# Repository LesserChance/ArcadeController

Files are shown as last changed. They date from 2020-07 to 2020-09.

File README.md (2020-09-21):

# ArcadeController
The goal of this project is to make an easily-swappable control panel for a homebuilt arcade. There are two PCBs that are designed to mate through a ribbon cable connection. By default, this setup will allow for any control panel to have a maximum of 2 joysticks and 14 buttons (22 total digital inputs), 6 axes (e.g. 6 spinners) and two USB devices. You can easily edit the program on the arduino to assure all of your control panels will work, though, for instance if you need more digital inputs and fewer axes.

As I build out more control panels I'll be adding pictures and diagrams of how everything operates.

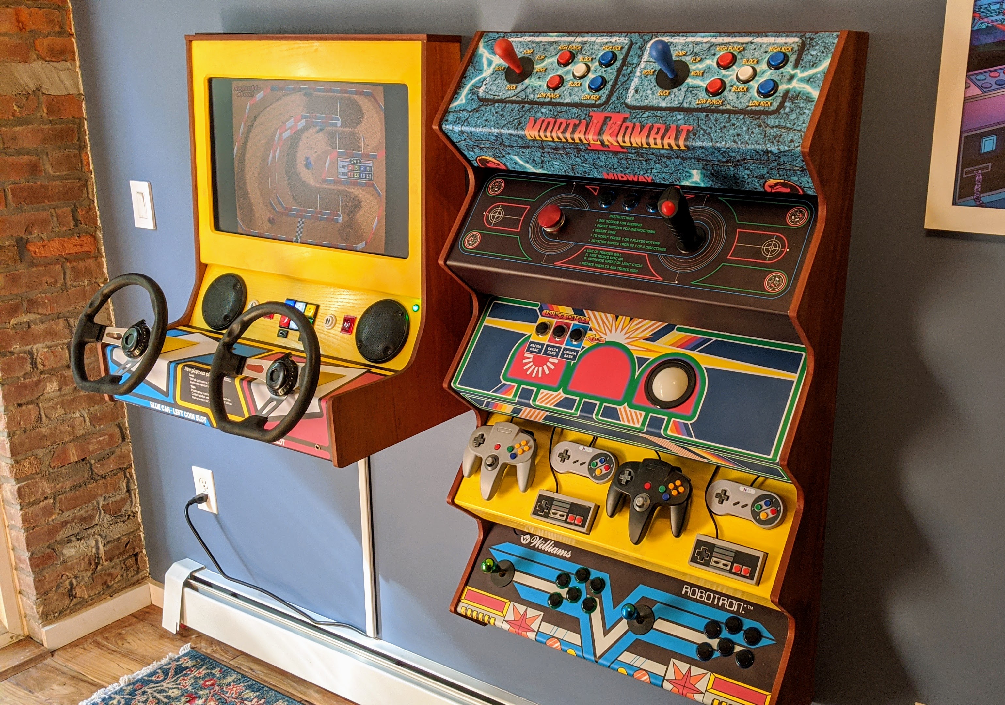
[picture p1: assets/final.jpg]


## Electronics
### PCB: Panel
One Panel PCB exists for each control panel. The Panel PCB exists as the interface between the controls (joysticks, trackballs, spinners, USB devices) and the Main interface. It is split into various sections. Full wiring diagrams can be found in the docs directory.

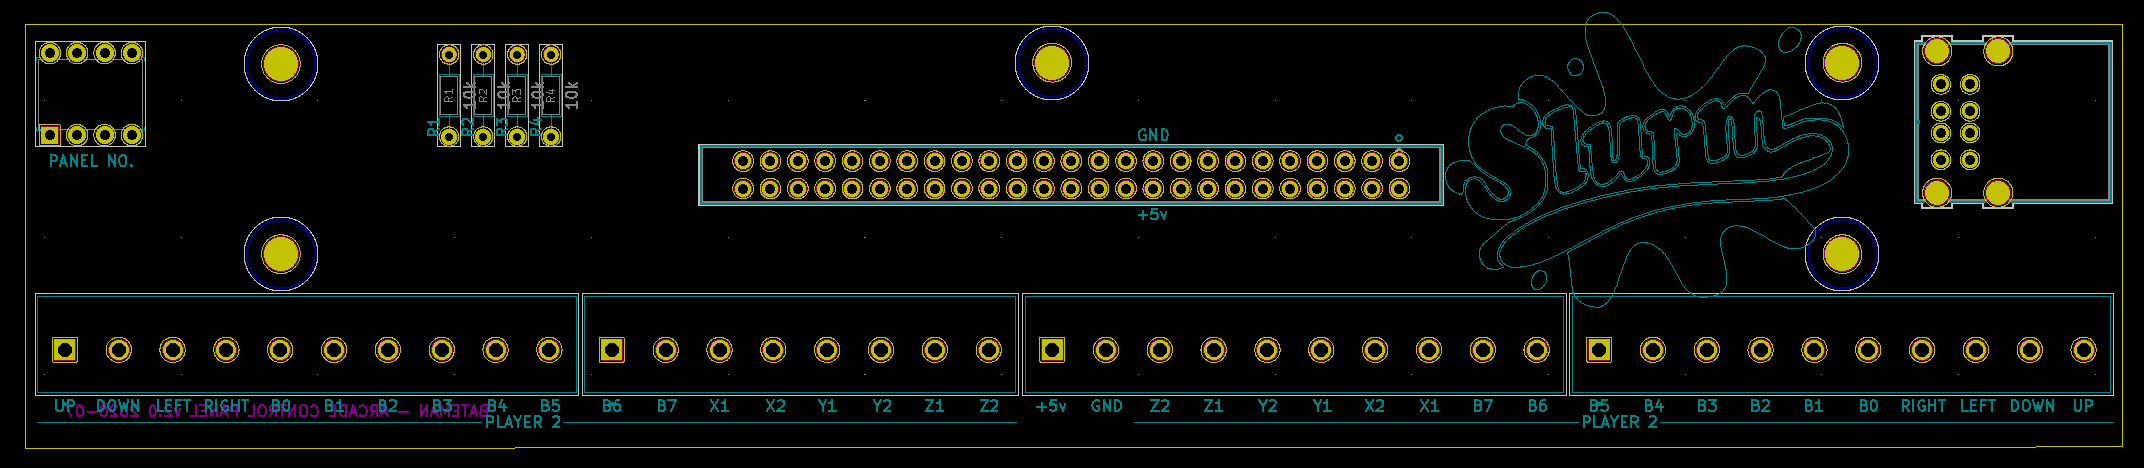
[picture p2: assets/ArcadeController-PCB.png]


**Player One** Connected to "Player One" Micro.  
*Up, Down, Left, Right, B0-5*: Four directional wires, 6 button wires. (note that B6, B7 are not wired to anything)  
*X1, X2, Y1, Y2, Z1, Z2*: These utilize interrupt pins on the arduinos, and are used for encoder connections (trackball, spinner)  

**Player Two** Connected to "Player Two" Micro.  
*Up, Down, Left, Right, B0-5*: Four directional wires, 6 button wires. (note that B6, B7 are not wired to anything)  
*X1, X2, Y1, Y2, Z1, Z2*: These utilize interrupt pins on the arduinos, and are used for encoder connections (trackball, spinner)  

**+5v/Ground** Pulls +5v and Ground from "Player One" Micro. Useful for LEDs/etc

**USB** These directly wire to USB connection on the main control panel. These can be used to directly connect USB devices to your computer. Unfortunately these dont seem to be working just yet!

**DIP switch** Used to identify which control panel this is. Allows for different programming on the arduinos per control panel.  

For detailed wiring information see [the pinmap](docs/pinmap.md).

### PCB: Main

The Main PCB is what connects to your computer through USB. In total it requires four open USB ports. Only One Main PCB is necessary. The main panels houses two Arduino Micros.

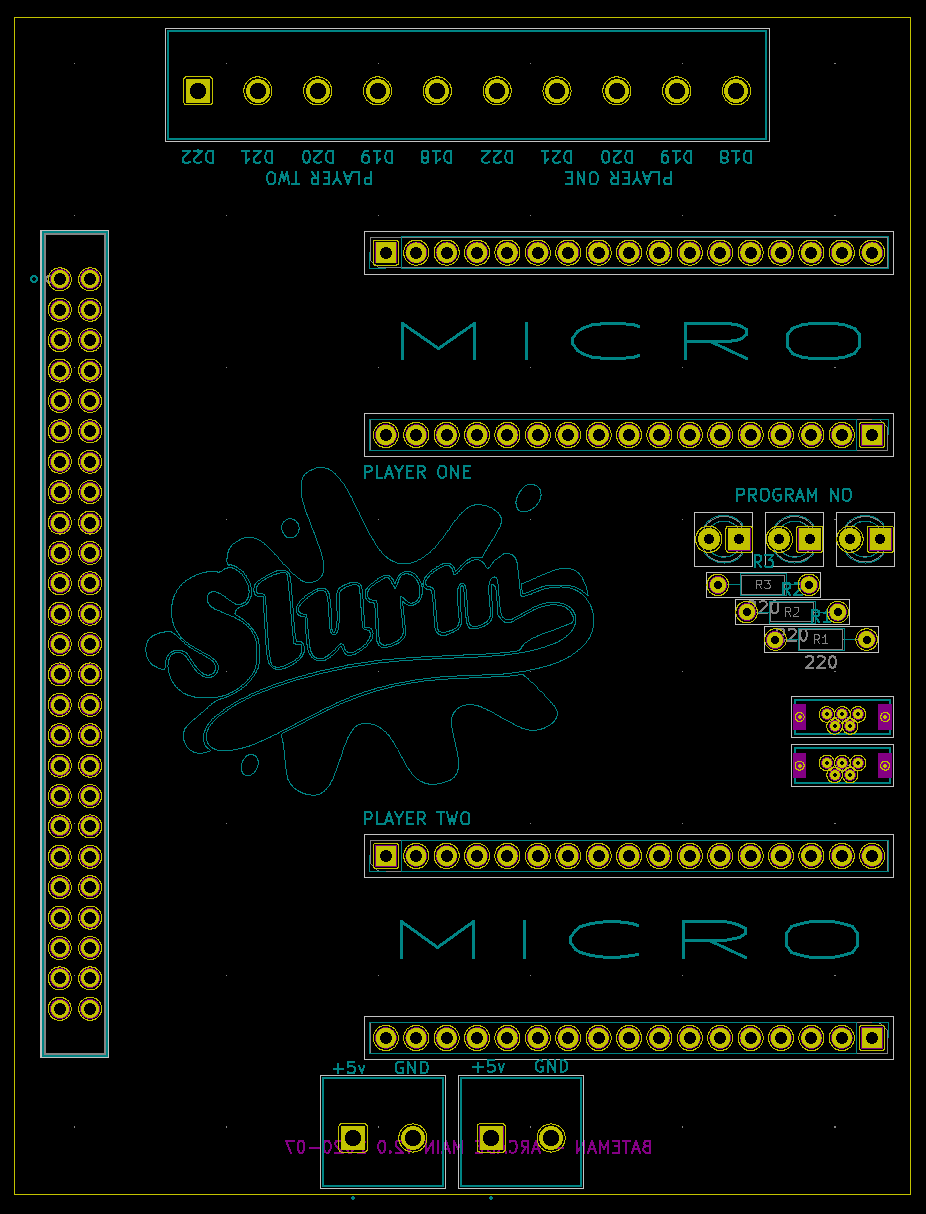
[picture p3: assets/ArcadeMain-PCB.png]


**Micro Headers** These are the positions where you plug in Arduino Micros.

**Screw in Terminals** These can be used for shared functions e.g. Player 1/2 Start/Coin as well as menu or function buttons. 6 are connected to "Player One" Micro, and another 6 are connected to "Player Two" Micro.

### Arduino

The program is built to run on an [Ardunio Micro](https://store.arduino.cc/usa/arduino-micro). Two Arduino Micros are required for two-player functionality. Player One and the two additional USB devices will work fine with just one, though, if you can get away with a maximum of 17 total digital inputs on any control panel.

When plugged in the Arduinos will be treated as a joystick/mouse/keyboard by the computer based on the code used for the control panel. The joystick, by default is 2 axis (X/Y) and 12 button.

---

Schematics were designed in [Kicad](https://kicad-pcb.org/). I print PCBS with [JLCPCB](jlcpcb.com/).

# Documents
### [Pinmap](docs/pinmap.md)
The pinmap outlines how connections are bridged between the PCBs and how they function by default through USB. Panel->Main->Arduino->Function

### [Wiring](docs/wiring.md)
The wiring doc outlines standard wiring for trackballs and spinners directly into the Panel PCB.

# Supplies
_Prices are USD, do not include shipping, and are as of July 2020._

Buy extra screw-in terminals to make more control panels, and buy the Panel PCBs in bulk. Given the below prices you could create 10 easily-swappable control panels for ~$80, and you may be able to find those screw terminals more cheaply, or decide to bypass those, just solder in your connections and have it all for ~$40. Of course the price of buttons/joysticks/trackballs/steering wheels/etc is additional.

| Component | Part | Supply | Cost | Count |
|---|---|---|---|---|
| Main | Arduino Micro | [Ardunio Store](https://store.arduino.cc/usa/arduino-micro-without-headers) | $12.30 | 2 |
| Main | PCB | [JLCPCB](jlcpcb.com/) | $7.00 | 1 (price is per 5 though - _minimum order_) |
| Main | Micro USB | [Digikey](https://www.digikey.com/product-detail/en/molex/0475890001/WM17143CT-ND/1832255) | $.87 | 2 |
| Main | Micro Pin Headers | [Digikey](https://www.digikey.com/product-detail/en/sullins-connector-solutions/PREC040SAAN-RC/S1012EC-40-ND/2774814) | $.51 | 2 |
| Main | Micro connection headers | [Digikey](https://www.digikey.com/product-detail/en/adafruit-industries-llc/598/1528-2537-ND/8299908) | $2.95 | 1 (cut each down to 17 pins) |
| Main | LEDs | Im sure you have some laying around | - | 3 |
| Main | Cable Header | [Digikey](https://www.digikey.com/product-detail/en/assmann-wsw-components/AWH-50G-E232-IDC/AE11157-ND/5050380) | $4.56 | 1 |
| Panel | PCB | [JLCPCB](jlcpcb.com/) | $12.00 | 1 (price was for 10) |
| Panel | USB Header | [Digikey](https://www.digikey.com/product-detail/en/assmann-wsw-components/AU-Y1008-2/AE11131-ND/5147142) | $1.07 | 1 |
| Panel | Ribbon Cable | [Digikey](https://www.digikey.com/product-detail/en/assmann-wsw-components/H3AAH-5018G/H3AAH-5018G-ND/1218717) | $3.27 | 1 |
| Panel | Cable Header | [Digikey](https://www.digikey.com/product-detail/en/sullins-connector-solutions/SBH11-PBPC-D25-ST-BK/S9176-ND/1990069) | $1.02 | 1 |
| Panel | DIP Switch | [Digikey](https://www.digikey.com/product-detail/en/cts-electrocomponents/208-4/CT2084-ND/20783) | $.69 | 1 |
| Main+Panel | Resistors | (3) 10k, 3 (220) | - | 6 |
| Main+Panel | Screw-in Terminal | [Digikey](https://www.digikey.com/products/en?keywords=TB001-500-12BE%20) | $1.73 | 5 (+4 for each additional panel) |

_Why do the PCBs have the Slurm logo on them? I dont know, I just really like Futurama and happened to have this image handy..._

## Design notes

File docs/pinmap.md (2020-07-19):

## Panel PCB
### Joystick
| Controller Input | Arduino | Arduino Pin | Function | Note |
|---|---|---|---|---|
| UP | 1/2 | SS/D17 | Player Up | Pin 17 is used for the LED, and MUST be a pulldown, wire this button to +5v, in retrospect I shouldn't have used this pin, as it looks like it randomly bounces. Ill probably swap it in the arduino code to the z axis pin or something. |
| DOWN | 1/2 | SCL/D3 | Player Down |  |
| LEFT | 1/2 |  A6/D4 | Player Left |  |
| RIGHT | 1/2 | D5 | Player Right |  |
| BUTTON 0 | 1/2 | A7/D6 | Player Button One |  |
| BUTTON 1 | 1/2 | D7 | Player Button Two |  |
| BUTTON 2 | 1/2 | A8/D8 | Player Button Three |  |
| BUTTON 3 | 1/2 | A9/D9 | Player Button Four |  |
| BUTTON 4 | 1/2 | A10/D10 | Player Button Five |  |
| BUTTON 5 | 1/2 | D11 | Player Button Six |  |
| BUTTON 6 | 1/2 | - | UNUSED |  |
| BUTTON 7 | 1/2 | - | UNUSED |  |

### AXIS
| Controller Input | Arduino | Arduino Pin | Function |
|---|---|---|---|
| X1 | 1/2 | RX/D0 | Player One Axis X - X1 |
| X2 | 1/2 | D15/SCK | Player One Axis X - X2 |
| Y1 | 1/2 | SDA/D2 | Player One Axis Y - Y1 |
| Y2 | 1/2 | D14/MISO | Player One Axis Y - Y2 |
| Z1 | 1/2 | TX/D1 | Player One Axis Z - Z1 |
| Z2 | 1/2 | D13 | Player One Axis Z - Z2 |

### USB ONE/TWO
| Controller Input | Arduino |  Arduino Pin | Function |
|---|---|---|---|
| RED | - | - | USB Device - Red |
| WHITE | - | - | USB Device - White |
| GREEN | - | - | USB Device - Green |
| BLACK | - | - | USB Device - Black |

### DIP SWITCH
| Controller Input | Arduino | Arduino Pin | Function | Note |
|---|---|---|---|---|
| DIP1 | 1/2 | A5/D23 | Program - Bit 0 |  |
| DIP2 | 1/2 | MOSI/D16 | Program - Bit 1 |  |
| DIP3 | 1/2 | A11/D12 | Program - Bit 2 |  |
| DIP4 | 1/2 | UNUSED | Program - Bit 3 |  |

## Main PCB
### SCREW IN TERMINALS
(analog pins)
| Main Input | Arduino |  Arduino Pin | Function |
|---|---|---|---|
| A0 | 1/2 | A0/D18 | CP Button One |
| A1 | 1/2 | A1/D19 | CP Button Two |
| A2 | 1/2 | A2/D20 | CP Button Three |
| A3 | 1/2 | A3/D21 | CP Button Four |
| A4 | 1/2 | A4/D22 | CP Button Five |

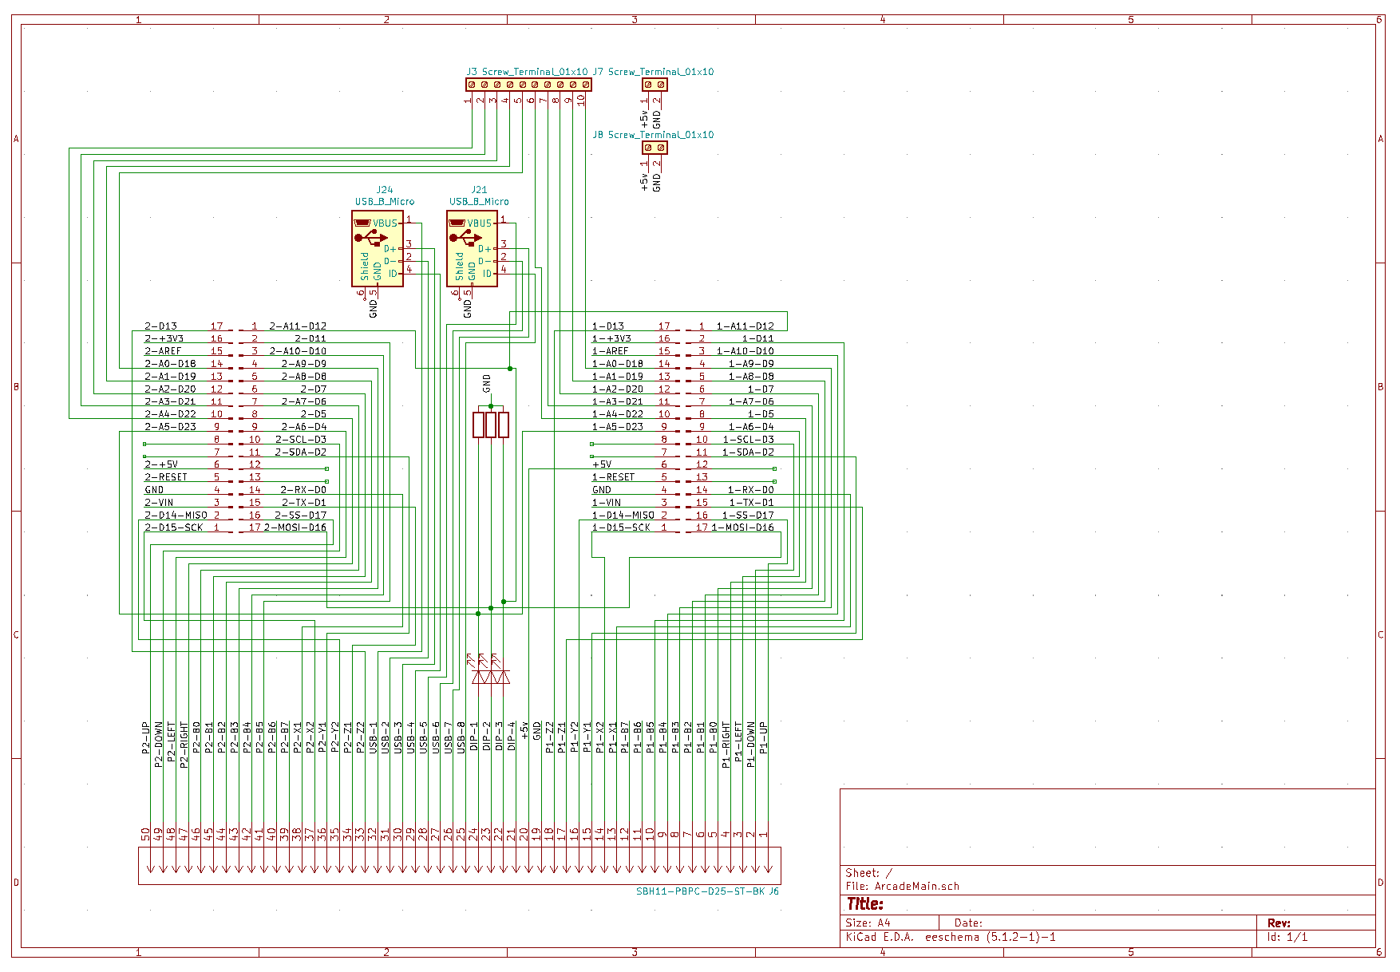
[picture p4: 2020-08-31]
assets/ArcadeMain-Schematic.png

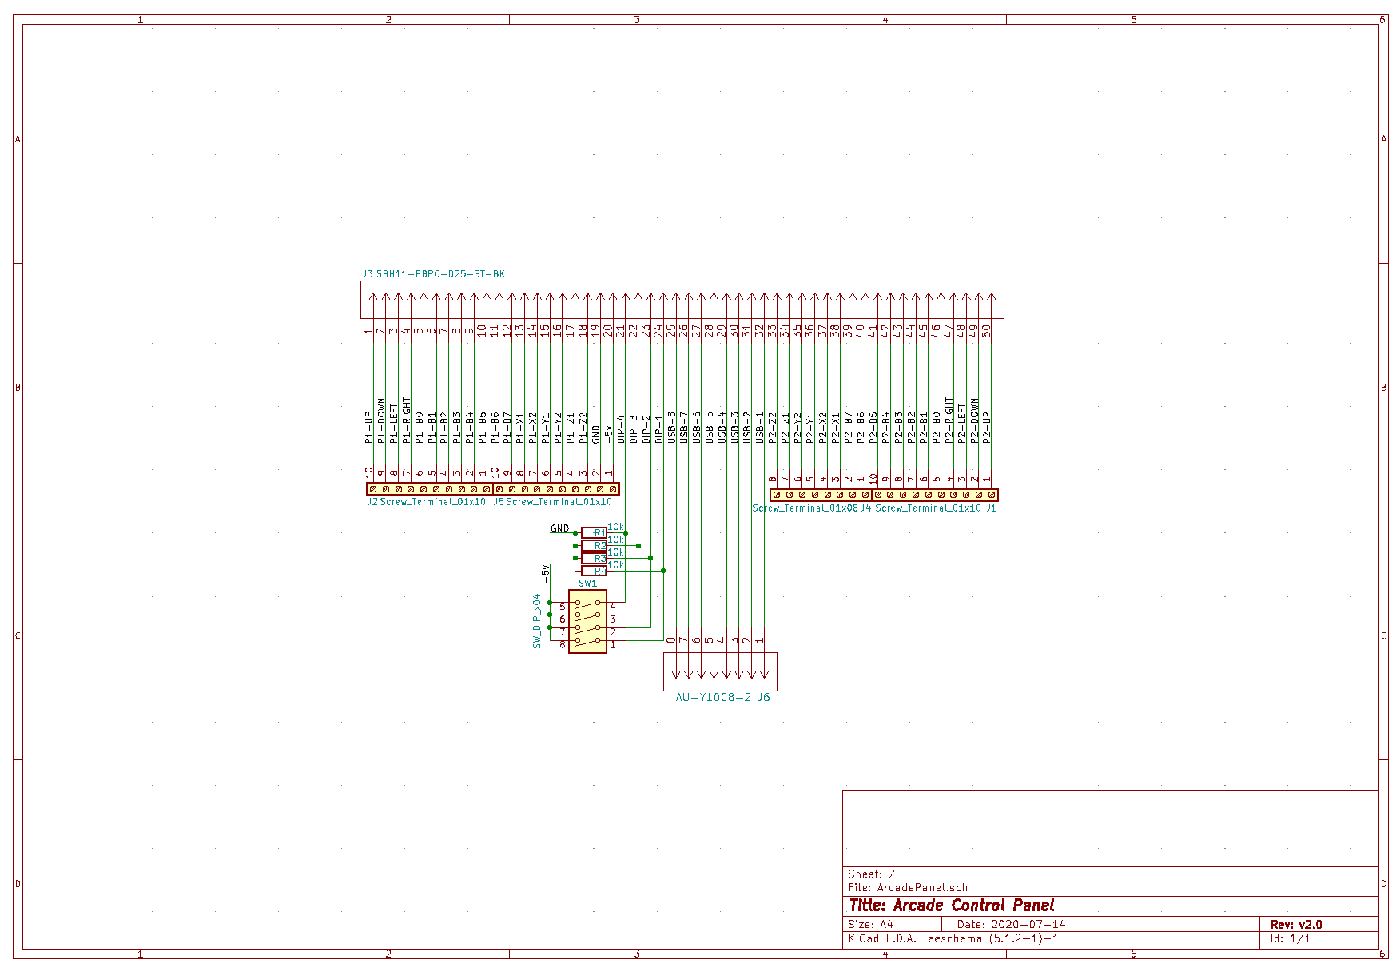
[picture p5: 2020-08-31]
assets/ArcadeController-Schematic.png

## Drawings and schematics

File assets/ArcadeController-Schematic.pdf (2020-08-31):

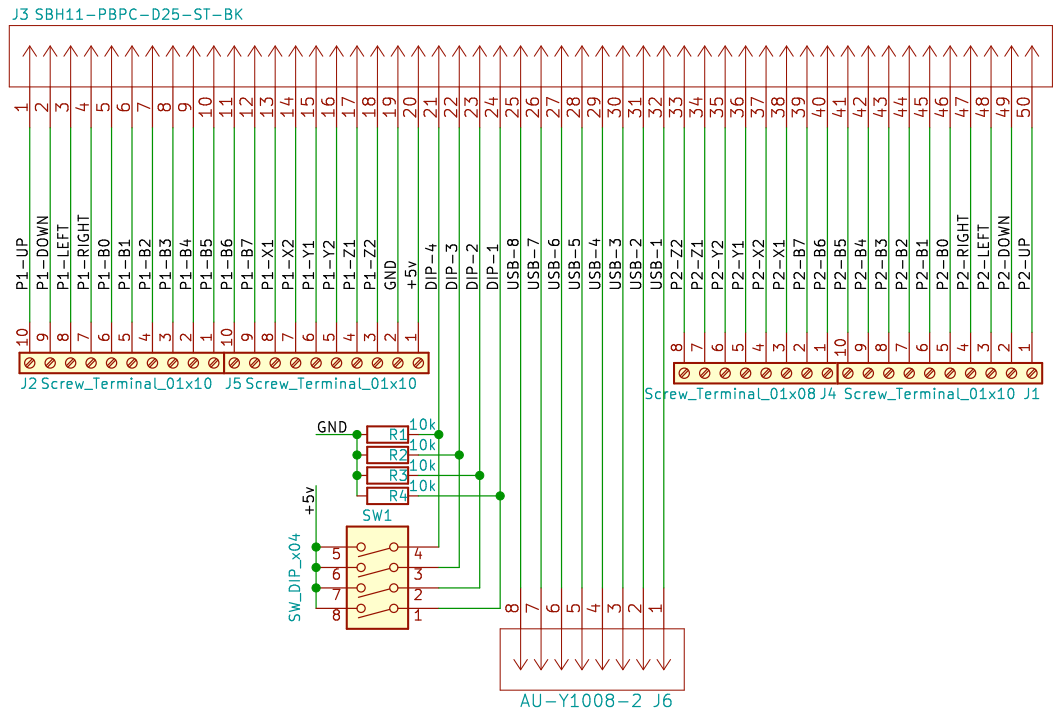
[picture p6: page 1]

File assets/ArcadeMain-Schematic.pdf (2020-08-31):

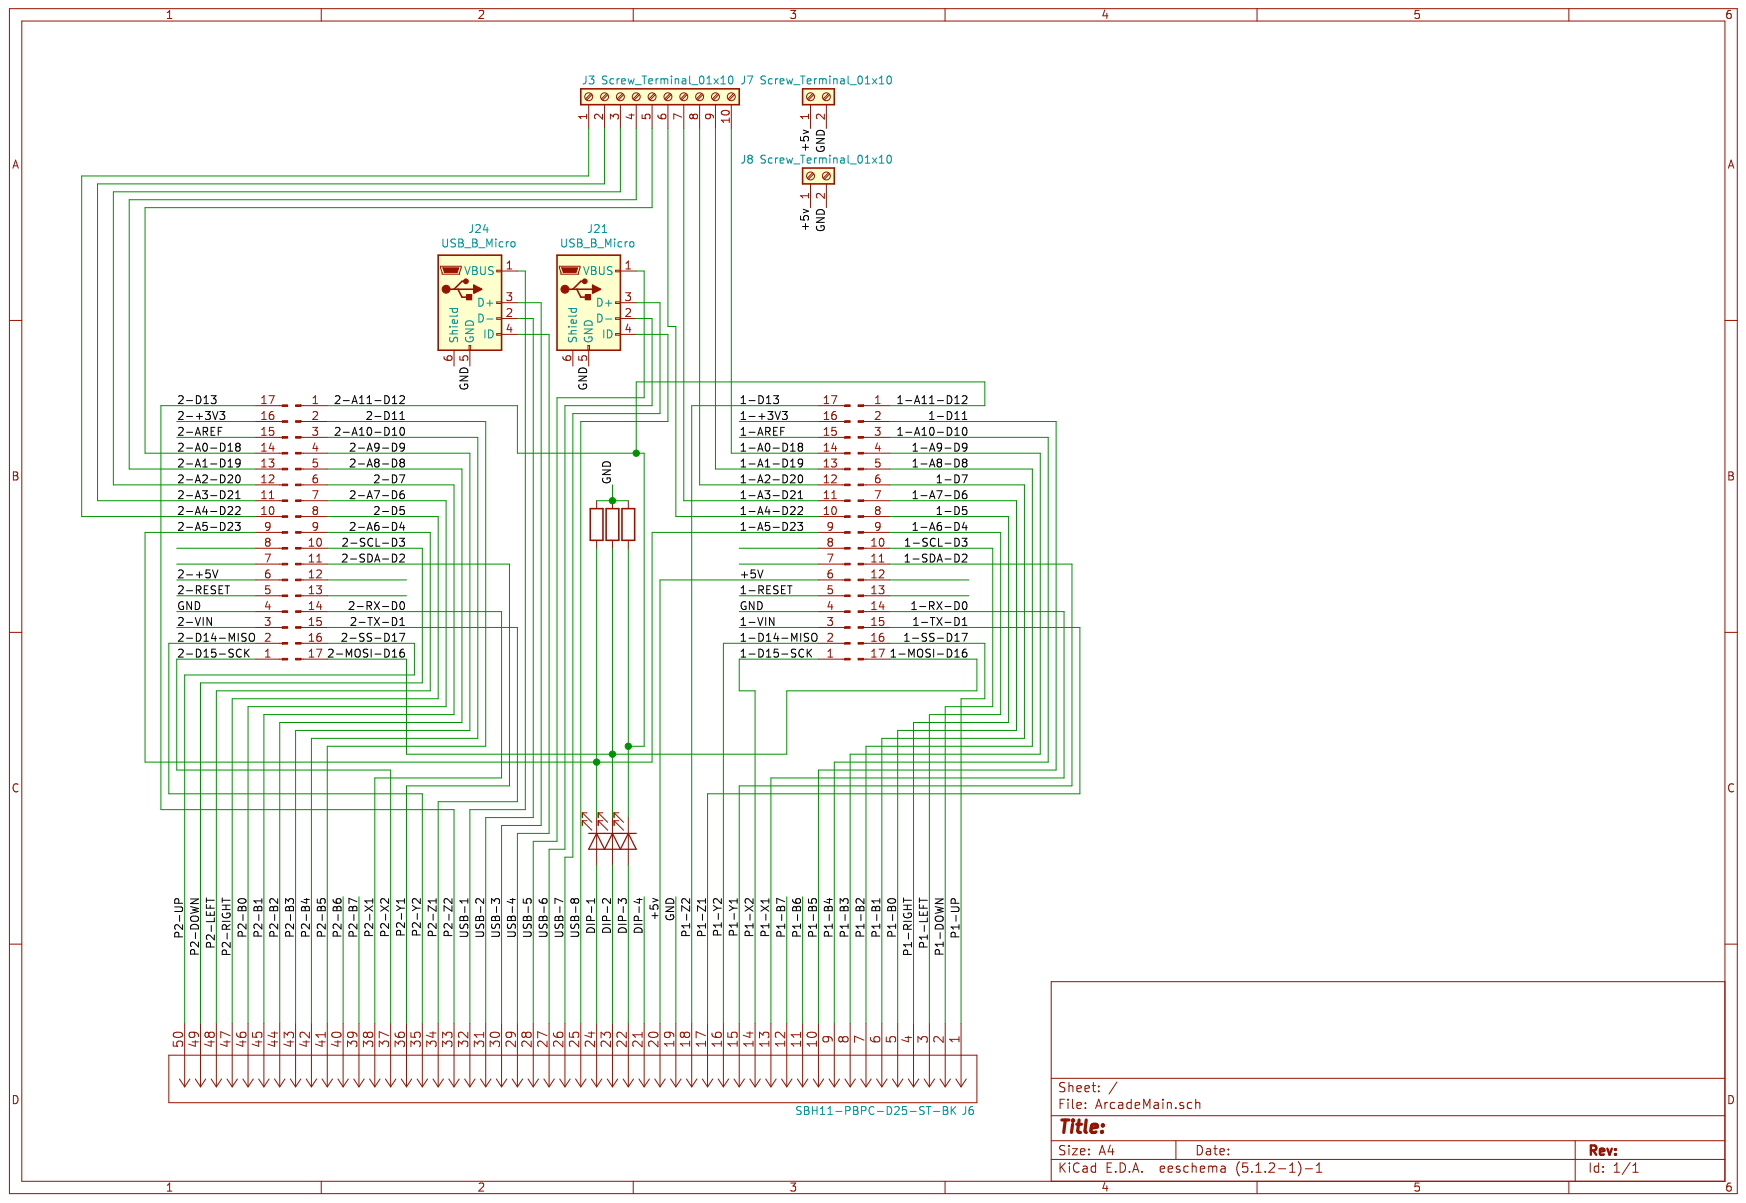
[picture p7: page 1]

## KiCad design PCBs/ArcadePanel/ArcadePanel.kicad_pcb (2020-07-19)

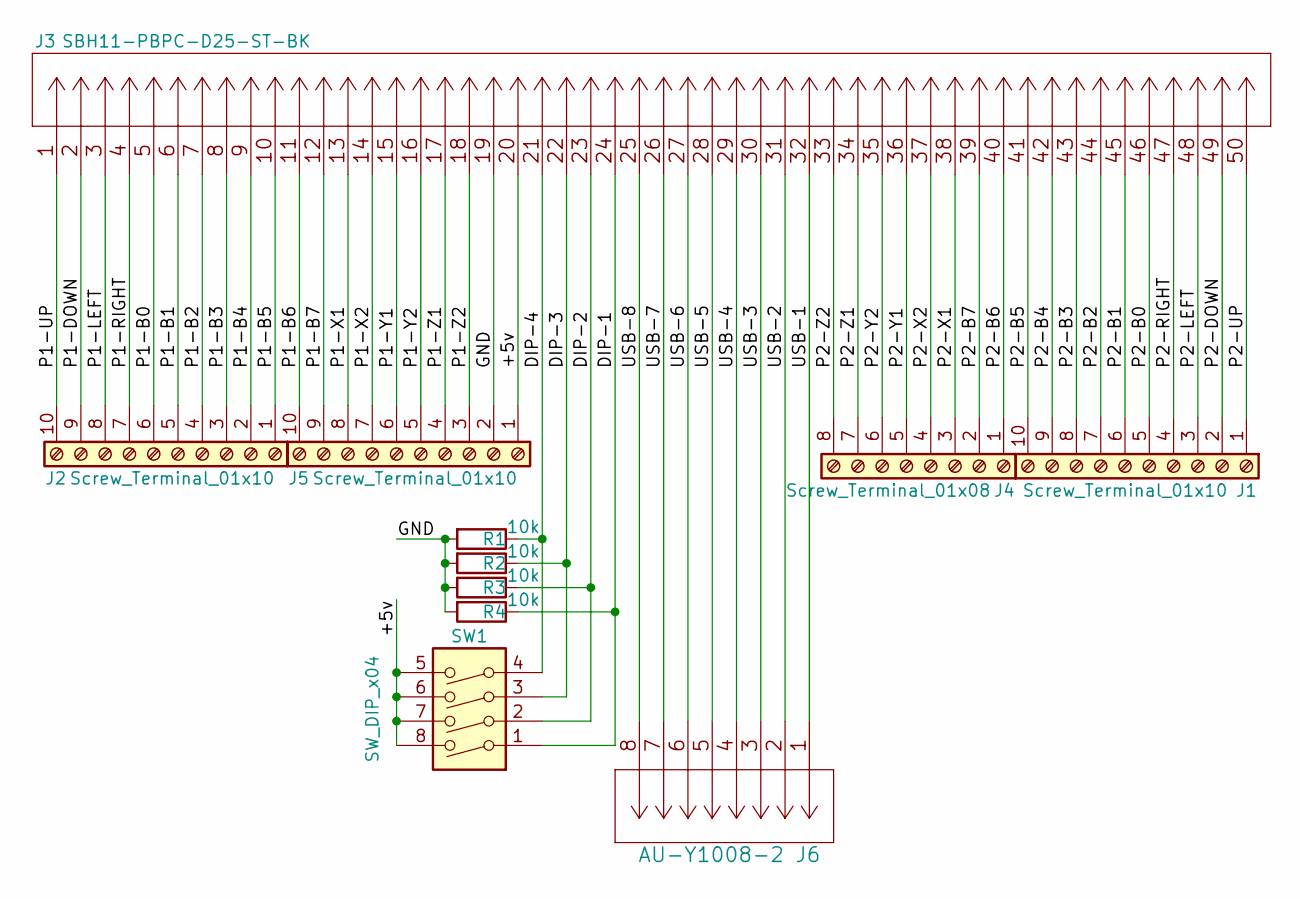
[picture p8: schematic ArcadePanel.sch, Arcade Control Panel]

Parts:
J1, J2, J5: Screw_Terminal_01x10; CUI_TB001-500-10BE
J3: SBH11-PBPC-D25-ST-BK
J4: Screw_Terminal_01x08; CUI_TB001-500-08BE
J6: AU-Y1008-2
R1, R2, R3, R4: 10k; R_Axial_DIN0204_L3.6mm_D1.6mm_P7.62mm_Horizontal
SW1: SW_DIP_x04; DIP-8_W7.62mm

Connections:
/+5v: J3.20, J5.1, SW1.5, SW1.6, SW1.7, SW1.8
/GND: J3.19, J5.2, R1.2, R2.2, R3.2, R4.2
/P1-B0: J2.6, J3.5
/P1-B1: J2.5, J3.6
/P1-B2: J2.4, J3.7
/P1-B3: J2.3, J3.8
/P1-B4: J2.2, J3.9
/P1-B5: J2.1, J3.10
/P1-B6: J3.11, J5.10
/P1-B7: J3.12, J5.9
/P1-DOWN: J2.9, J3.2
/P1-LEFT: J2.8, J3.3
/P1-RIGHT: J2.7, J3.4
/P1-UP: J2.10, J3.1
/P1-X1: J3.13, J5.8
/P1-X2: J3.14, J5.7
/P1-Y1: J3.15, J5.6
/P1-Y2: J3.16, J5.5
/P1-Z1: J3.17, J5.4
/P1-Z2: J3.18, J5.3
/P2-B0: J1.5, J3.46
/P2-B1: J1.6, J3.45
/P2-B2: J1.7, J3.44
/P2-B3: J1.8, J3.43
/P2-B4: J1.9, J3.42
/P2-B5: J1.10, J3.41
/P2-B6: J3.40, J4.1
/P2-B7: J3.39, J4.2
/P2-DOWN: J1.2, J3.49
/P2-LEFT: J1.3, J3.48
/P2-RIGHT: J1.4, J3.47
/P2-UP: J1.1, J3.50
/P2-X1: J3.38, J4.3
/P2-X2: J3.37, J4.4
/P2-Y1: J3.36, J4.5
/P2-Y2: J3.35, J4.6
/P2-Z1: J3.34, J4.7
/P2-Z2: J3.33, J4.8
unnamed: J3.21, R1.1, SW1.4
unnamed: J3.22, R2.1, SW1.3
unnamed: J3.23, R3.1, SW1.2
unnamed: J3.24, R4.1, SW1.1
unnamed: J3.25, J6.8
unnamed: J3.26, J6.7
unnamed: J3.27, J6.6
unnamed: J3.28, J6.5
unnamed: J3.29, J6.4
unnamed: J3.30, J6.3
unnamed: J3.31, J6.2
unnamed: J3.32, J6.1

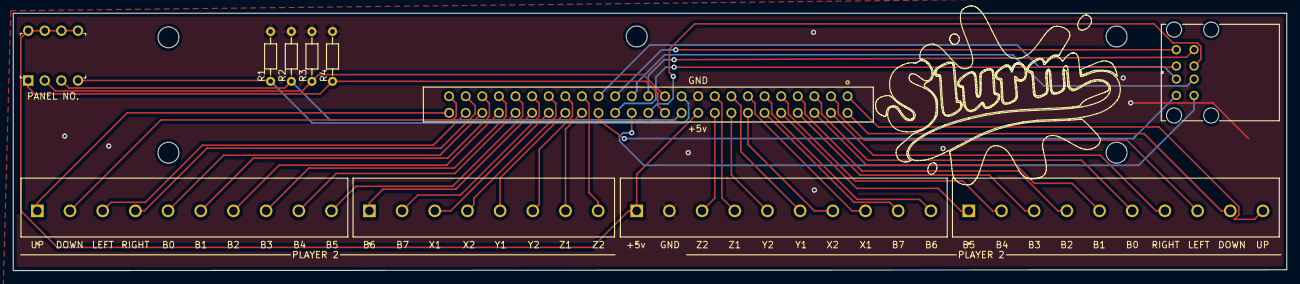
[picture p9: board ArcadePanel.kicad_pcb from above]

Board: 2 copper layers, 194.8 x 39.4 mm, 16 parts (0 on the bottom side), 50 nets.

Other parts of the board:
4, 4#2, 4#3, 4#4, 4#5: MountingHole_3.2mm_M3

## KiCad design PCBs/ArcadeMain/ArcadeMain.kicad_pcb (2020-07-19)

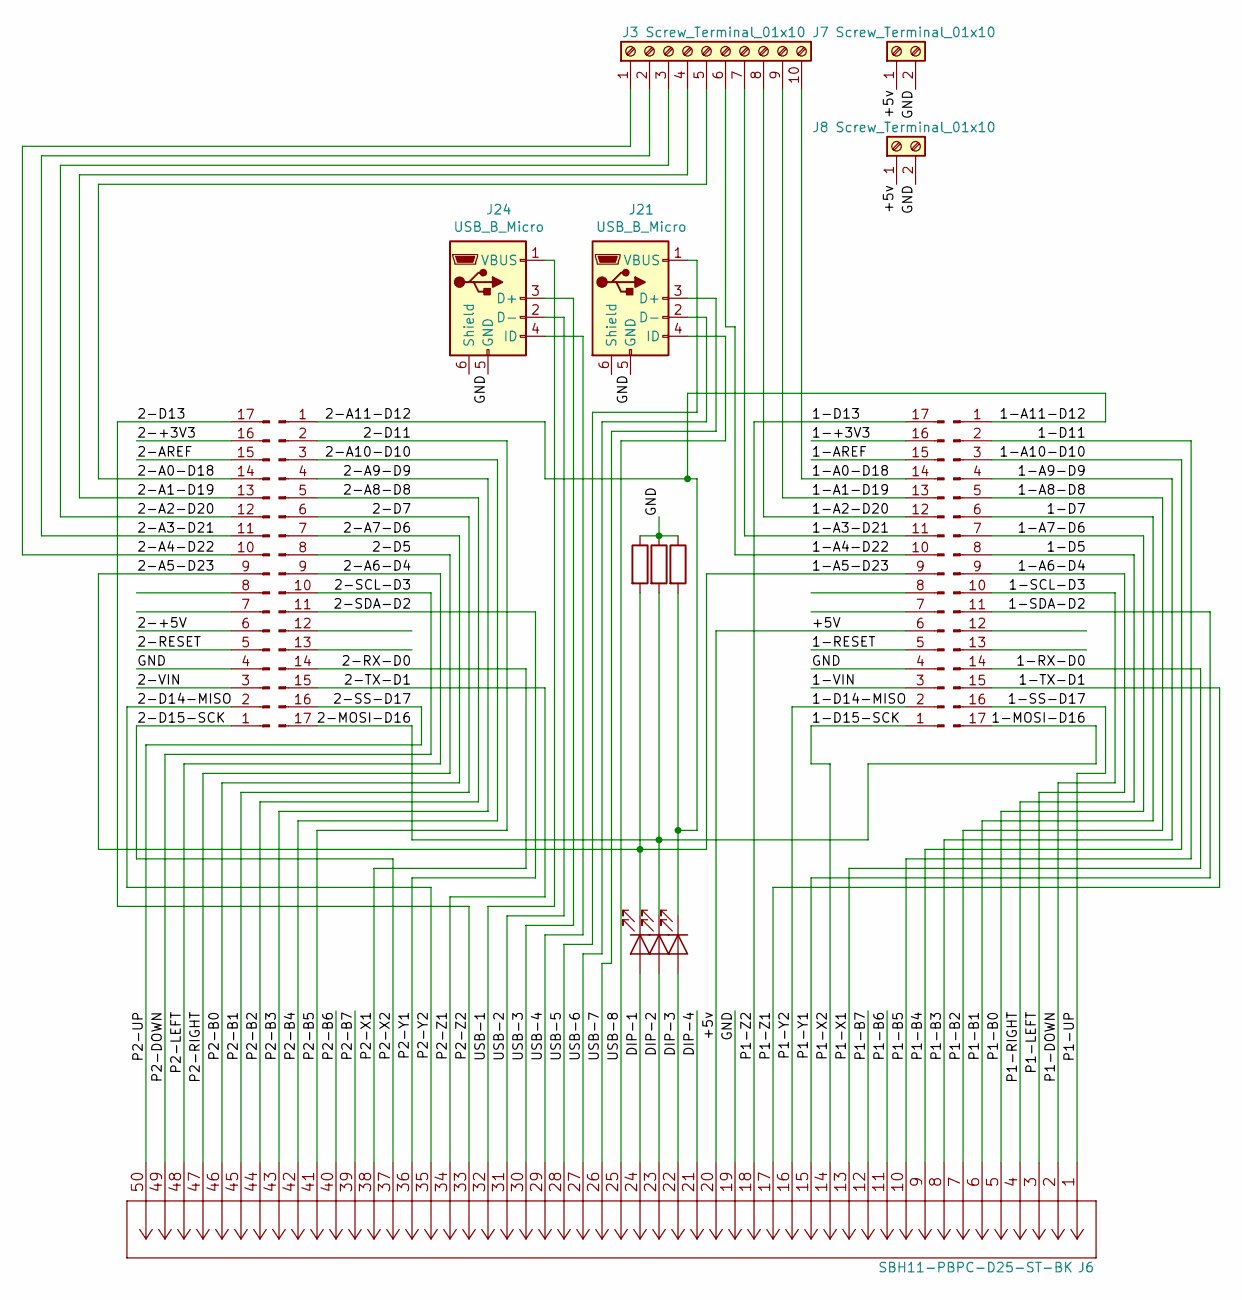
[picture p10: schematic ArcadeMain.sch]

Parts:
D1, D2, D3: LED; LED_D3.0mm
J1, J2, J4, J5: Conn_01x17_Male; PinHeader_1x17_P2.54mm_Vertical
J3: Screw_Terminal_01x10; CUI_TB001-500-10BE
J6: SBH11-PBPC-D25-ST-BK
J7, J8: Screw_Terminal_01x10; CUI_TB001-500-02BE
J21, J24: USB_B_Micro; GCT_USB3131-XX-0230-X_REVB
R1, R2, R3: 220; R_Axial_DIN0204_L3.6mm_D1.6mm_P7.62mm_Horizontal

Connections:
/1-+3V3: J1.16
/1-A0-D18: J1.14, J3.10
/1-A1-D19: J1.13, J3.9
/1-A2-D20: J1.12, J3.8
/1-A3-D21: J1.11, J3.7
/1-A4-D22: J1.10, J3.6
/1-A5-D23: D1.1 (K), J1.9, J4.9, R1.2
/1-A6-D4: J2.9, J6.3
/1-A7-D6: J2.7, J6.5
/1-A8-D8: J2.5, J6.7
/1-A9-D9: J2.4, J6.8
/1-A10-D10: J2.3, J6.9
/1-A11-D12: D3.1 (K), J2.1, J5.1, R3.2
/1-AREF: J1.15
/1-D5: J2.8, J6.4
/1-D7: J2.6, J6.6
/1-D11: J2.2, J6.10
/1-D13: J1.17, J6.18
/1-D14-MISO: J1.2, J6.16
/1-D15-SCK: J1.1, J6.14
/1-MOSI-D16: D2.1 (K), J2.17, J5.17, R2.2
/1-RESET: J1.5
/1-RX-D0: J2.14, J6.13
/1-SCL-D3: J2.10, J6.2
/1-SDA-D2: J2.11, J6.15
/1-SS-D17: J2.16, J6.1
/1-TX-D1: J2.15, J6.17
/1-VIN: J1.3
/2-+3V3: J4.16
/2-+5V: J4.6
/2-A0-D18: J3.5, J4.14
/2-A1-D19: J3.4, J4.13
/2-A2-D20: J3.3, J4.12
/2-A3-D21: J3.2, J4.11
/2-A4-D22: J3.1, J4.10
/2-A6-D4: J5.9, J6.48
/2-A7-D6: J5.7, J6.46
/2-A8-D8: J5.5, J6.44
/2-A9-D9: J5.4, J6.43
/2-A10-D10: J5.3, J6.42
/2-AREF: J4.15
/2-D5: J5.8, J6.47
/2-D7: J5.6, J6.45
/2-D11: J5.2, J6.41
/2-D13: J4.17, J6.33
/2-D14-MISO: J4.2, J6.35
/2-D15-SCK: J4.1, J6.37
/2-RESET: J4.5
/2-RX-D0: J5.14, J6.38
/2-SCL-D3: J5.10, J6.49
/2-SDA-D2: J5.11, J6.36
/2-SS-D17: J5.16, J6.50
/2-TX-D1: J5.15, J6.34
/2-VIN: J4.3
/+5V: J1.6, J6.20, J7.1, J8.1
/DIP-1: D1.2 (A), J6.24
/DIP-2: D2.2 (A), J6.23
/DIP-3: D3.2 (A), J6.22
/DIP-4: J6.21
/GND: J1.4, J4.4, J6.19, J7.2, J8.2, J21.5 (GND), J24.5 (GND), R1.1, R2.1, R3.1
/P1-B6: J6.11
/P1-B7: J6.12
/P2-B6: J6.40
/P2-B7: J6.39
/USB-1: J6.32, J24.1 (VBUS)
/USB-2: J6.31, J24.2 (D-)
/USB-3: J6.30, J24.3 (D+)
/USB-4: J6.29, J24.4 (ID)
/USB-5: J6.28, J21.1 (VBUS)
/USB-6: J6.27, J21.2 (D-)
/USB-7: J6.26, J21.3 (D+)
/USB-8: J6.25, J21.4 (ID)

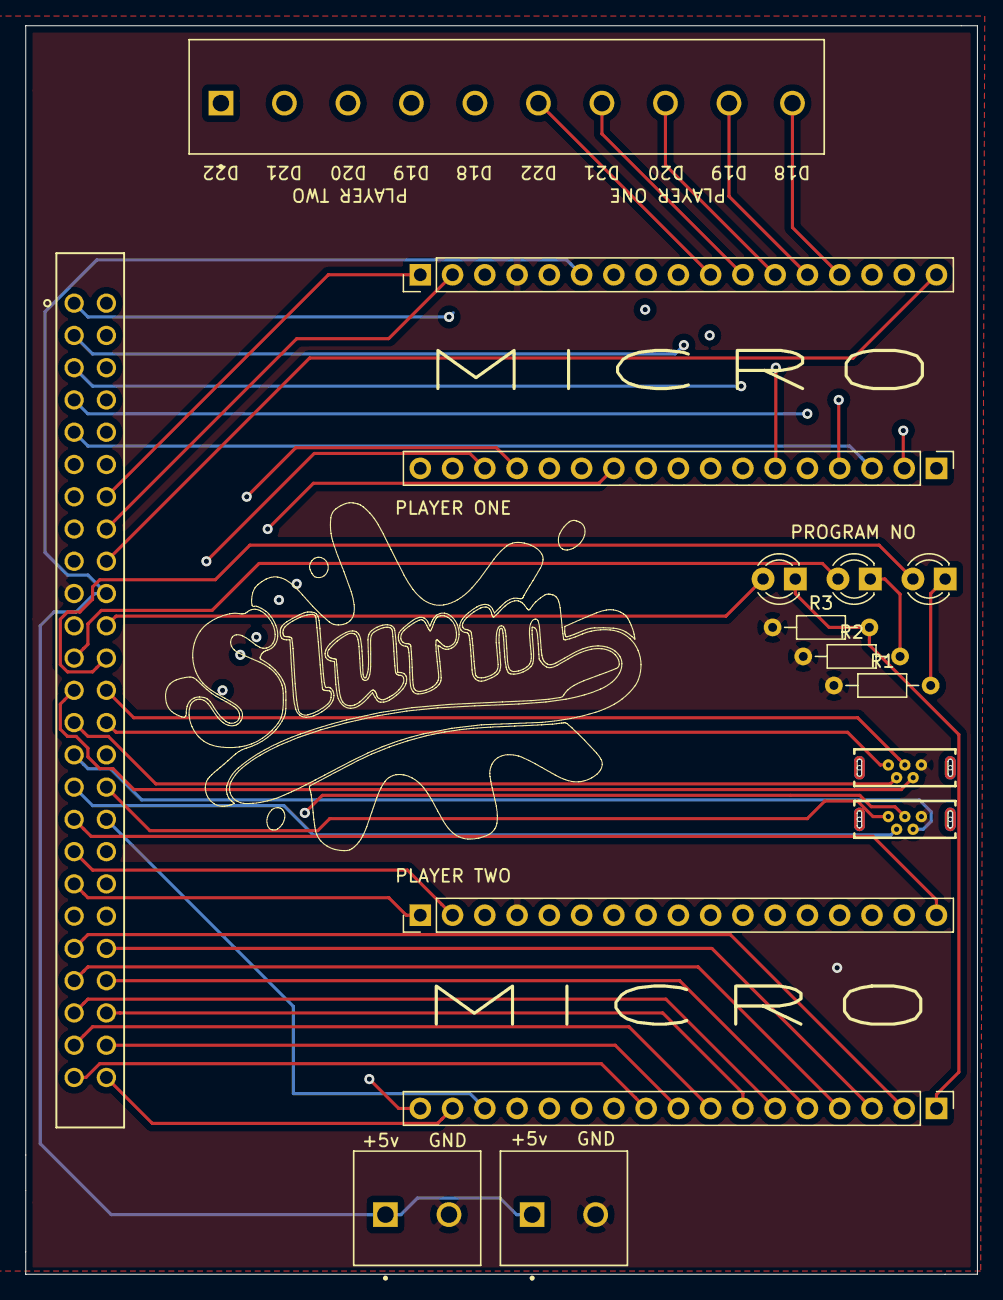
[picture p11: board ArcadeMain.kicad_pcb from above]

Board: 4 copper layers, 74.9 x 98.3 mm, 16 parts (0 on the bottom side), 58 nets.

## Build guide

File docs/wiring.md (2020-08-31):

# Wiring
Using [Ultimarc](https://www.ultimarc.com/) trackballs and spinners, this would be the standard wiring.

### Trackball
| Wire | Connection | Function |
|---|---|---|
| Red | A | 5 Volts |
| Black | A | Ground |
| Purple | A | X1 |
| Blue | A | X2 |
| Red | B | 5 Volts |
| Black | B | Ground |
| Yellow | B | Y1 |
| Green | B | Y2 |

## Spinner
| Wire | Function |
|---|---|
| Brown | 5 Volts |
| White | Ground |
| Yellow | X1 |
| Green | X2 |

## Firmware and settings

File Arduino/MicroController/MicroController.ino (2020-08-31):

// Library imports
#include <Encoder.h>
#include <Joystick.h>
#include <Mouse.h>
#include <Keyboard.h>
#include <Servo.h>

// Local imports
#include "pinmap.h"
#include "globals.h"
#include "axis.h"
#include "panel-0.h"
#include "panel-1.h"
#include "panel-2.h"
#include "panel-3.h"

void setup() {
  Serial.begin(115200);
  
  for (byte i = 0; i < sizeof(CP_BUTTON_PIN); i++) {
    pinMode(CP_BUTTON_PIN[i], INPUT_PULLUP);
  }

  panel0_setup();
  gamepad.begin(false);
  Mouse.begin();
  Keyboard.begin();
}

void loop(){
  // Read DIP state to see if joystick has changed
  setActivePanel();

  // Read any serial data
  if (Serial.available() > 0) {
    readSerialData();
  }

  // set a neutral state to debounce panel changes
  gamepad.setXAxis(AXIS_LIMIT);
  gamepad.setYAxis(AXIS_LIMIT);
  for (byte i = 0; i < sizeof(JOY_BUTTON_PIN); i++) {
    gamepad.setButton(i, 0);
  }

  // Control Panel
  for (byte i = 0; i < sizeof(CP_BUTTON_PIN); i++) {
    if (!digitalRead(CP_BUTTON_PIN[i])) {
      if (!cpButtonActive[PLAYER][i]) {
        cpButtonActive[PLAYER][i] = true;
        Keyboard.press(CP_BUTTON_KEY[PLAYER][i]);
        delay(40); // need this to get keys to read accurately, would be better to continue to allow execution and use a timer to release the key
      }
    } else if (cpButtonActive[PLAYER][i]) {
      cpButtonActive[PLAYER][i] = false;
      Keyboard.releaseAll();
    }
  }

  switch (activePanel) {
    case 0:
      panel0_loop();
      break;
    case 1:
      panel1_loop();
      break;
    case 2:
      panel2_loop();
      break;
    case 3:
      panel3_loop();
      break;
  }
  
  gamepad.sendState();
  delay(10);
}

void setActivePanel() {
  int newActivePanel = 0;
  
  bitWrite(newActivePanel, 0, digitalRead(PANEL_DIP_PIN[0]));
  bitWrite(newActivePanel, 1, digitalRead(PANEL_DIP_PIN[1]));
  bitWrite(newActivePanel, 2, digitalRead(PANEL_DIP_PIN[2]));

  if (newActivePanel != activePanel) {
    activePanel = newActivePanel;
    
    switch (activePanel) {
      case 0:
        panel0_setup();
        break;
      case 1:
        panel1_setup();
        break;
      case 2:
        panel2_setup();
        break;
      case 3:
        panel3_setup();
        break;
    }
  }
}

void readSerialData() {
  // serial data format x:y (x = 4 or 8 for joystick type, y = number of buttons to light)
  byte ndx = 0;
  char rc;
  char receivedData[3];
  boolean exitRead = false;
  
  while (Serial.available() > 0 && !exitRead && ndx < 3) {
    rc = Serial.read();
  
    if (rc != SERIAL_TERMINATE) {
      receivedData[ndx] = rc;
      ndx++;
    } else {
      boolean controllerIs4Way = (receivedData[0] == CONTROLLER_4_WAY);
      int buttonCount = (int) receivedData[2] - 48; // convert char to int

      Serial.print("ACK");
      
      switch (activePanel) {
        case 0:
          panel0_handleSerialData(controllerIs4Way, buttonCount);
          break;
        case 1:
          panel1_handleSerialData(controllerIs4Way, buttonCount);
          break;
        case 2:
          panel2_handleSerialData(controllerIs4Way, buttonCount);
          break;
        case 3:
          panel3_handleSerialData(controllerIs4Way, buttonCount);
          break;
      }
      exitRead = true;
    }
  }
}

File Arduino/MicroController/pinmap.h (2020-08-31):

#ifndef _PINMAP_H
#define _PINMAP_H

const byte PIN_UP = 17; // dont use this pin, pin 17 is used for the onboard LED and seems to randomly bounce
const byte PIN_DOWN = 3;
const byte PIN_LEFT = 4;
const byte PIN_RIGHT = 5;

const byte PIN_B0 = 6;
const byte PIN_B1 = 7;
const byte PIN_B2 = 8;
const byte PIN_B3 = 9;
const byte PIN_B4 = 10;
const byte PIN_B5 = 11;

const byte PIN_X1 = 0;
const byte PIN_X2 = 15;
const byte PIN_Y1 = 2;
const byte PIN_Y2 = 14;
const byte PIN_Z1 = 1;
const byte PIN_Z2 = 13;

const byte PIN_DIP_0 = 23;
const byte PIN_DIP_1 = 16;
const byte PIN_DIP_2 = 12;

const byte PIN_MAIN_18 = 18;
const byte PIN_MAIN_19 = 19;
const byte PIN_MAIN_20 = 20;
const byte PIN_MAIN_21 = 21;
const byte PIN_MAIN_22 = 22;

#endif

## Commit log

2020-07-11 Initial Docs
    [ArcadeMain-B_Cu.gbr, ArcadeMain-B_Mask.gbr, ArcadeMain-B_Paste.gbr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]
2020-07-11 Add Schematic PDFs
2020-07-19 v2 PCB revisions: switch to ribbon cable rather than PCB edge, add DIP switch for panel identifications
    [ArcadeMain-B_Cu.gbr, ArcadeMain-B_Mask.gbr, ArcadeMain-B_Paste.gbr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]
2020-07-26 Update skecth to use mouse and keyboard.
    Retroarch only allows a single controller to control the menu functions so mapping the main panel to keyboard keys gets around this. Additionally using joystick axes was not working for trackball input, switching to mouse input directly works.
    [MicroController.ino]
2020-07-29 Panel 0 updates
    Panel 0 is now set up to use a 4 to 8 way servo controlled restrictor plate as well as button leds. controls are parses with the standard mame controls.xml file. Additionally split out the arduino co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
2020-07-30 Button LED fixes
    Some quick fixes after actually hooking everything up and trying it out
    [globals.h, panel-0.h, panel-1.h]
2020-07-31 Move serial functionality up
    even if a panel doesnt need to read it, it shouldnt fail to listen
    [MicroController.ino, globals.h, panel-0.h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]
2020-08-31 Update Schematic references

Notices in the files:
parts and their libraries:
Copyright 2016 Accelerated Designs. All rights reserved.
